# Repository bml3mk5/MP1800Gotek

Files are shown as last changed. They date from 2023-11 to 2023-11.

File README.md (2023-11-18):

# ディスクインターフェース for MP-1800 / MP-1805 on 日立ベーシックマスターレベル３

## フォルダ構成

    Board/ ......................... 基板設計(KiCAD Version 6)

-----
# Disk Interface for MP-1800 / MP-1805 on HITACH BASIC MASTER LEVEL3

## Folders:

    Board/ ......................... Circuit board design(KiCAD Version 6)

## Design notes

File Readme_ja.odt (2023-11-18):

# 日立ベーシックマスターレベル３用

# ディスクインターフェース for MP-1800 / MP-1805

Designed by Sasaji 2023 Rev. 0.2.2

フロッピーディスクドライブとFDインターフェースMP-1800 / MP-1805の間に接続する拡張ボードです。

日立ベーシックマスターレベル３/マークII/マーク5で使用できます。

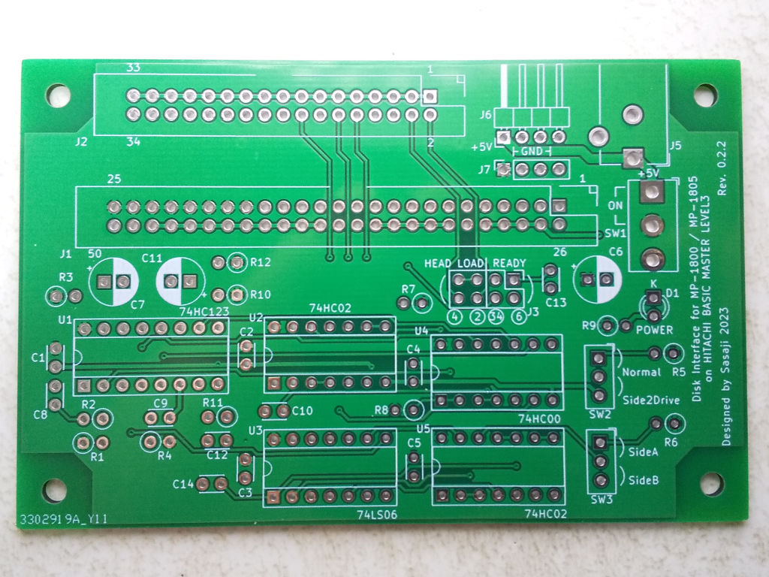
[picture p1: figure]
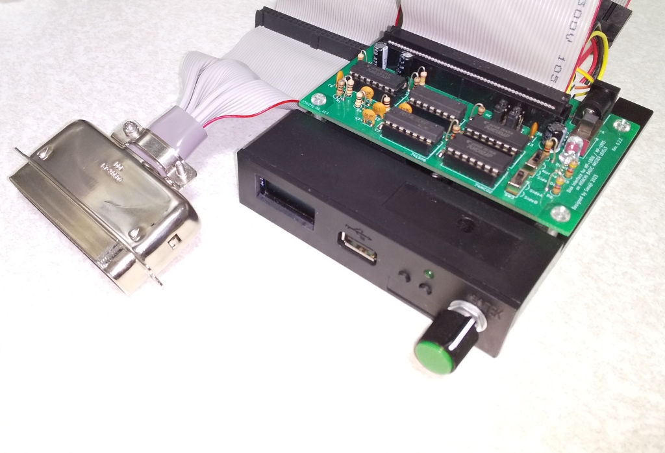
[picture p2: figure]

GOTEKを接続したところ

# 準備するもの

この基板を使用するには、以下のものを別途用意する必要があります。

- 本体側にFDインターフェースカード MP-1800またはMP-1805があること。
- FDDはエミュレータ(GOTEK)または2Dのもの。
- 電源：+5V, 1A以上（スイッチングACアダプタ など）
- 本体側と接続するケーブル：50ピンアンフェノール　⇔ 50ピン IDCコネクタ(2.54mmピッチ x2列)
- FDD側と接続するケーブル：34ピンIDCコネクタケーブル(2.54mmピッチ x2列)

# 各部の役割

電源入力 ＋５V DCジャック （中心が＋） 電源入力 ＋５V EIコネクタ (+5V,Gnd,Gnd,N/C) FDDと 接続 本体側と 接続 電源出力 ＋５V FDDに接続 （電源スイッチと連動） 電源スイッチ ジャンパー Side2Drive 切換スイッチ + - サイド 切換スイッチ

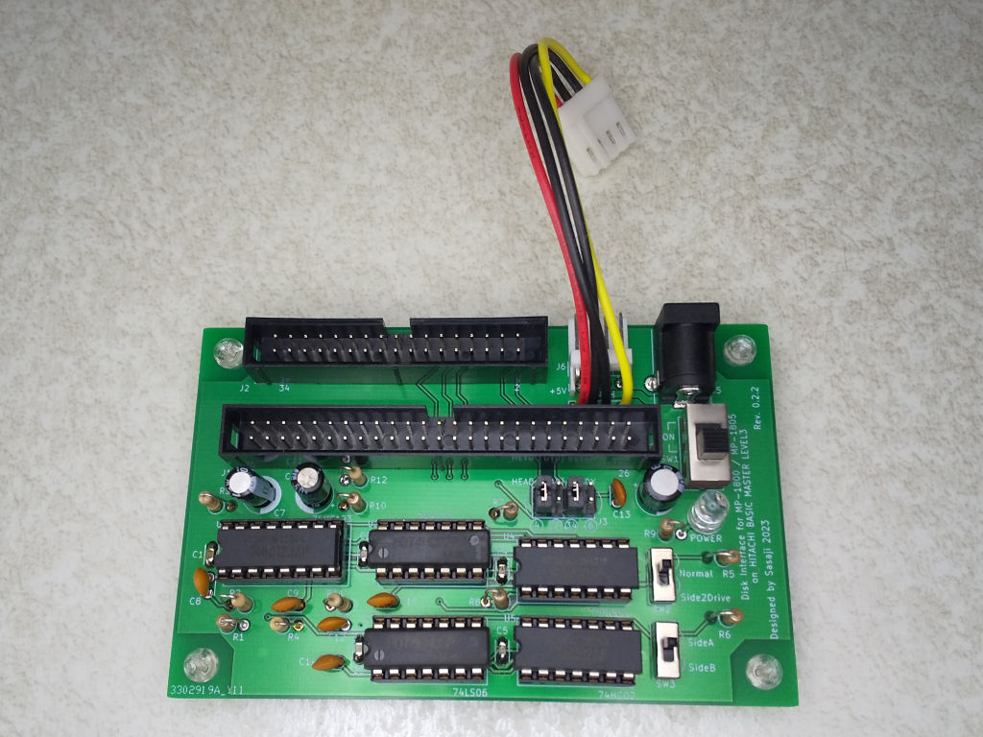
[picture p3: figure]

# ジャンパピン

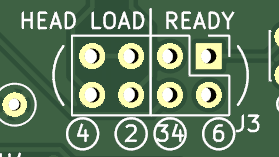
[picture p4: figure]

READY:

FDDからくるREADY信号がどのピンから来ているかを選択します。

ピン34 または ピン6

どちらかを縦方向にショートさせてください。

HEAD LOAD:

本体側からくるHEAD LOAD信号をどのピンに送るか選択します。

ピン4 または ピン2

どちらかを縦方向にショートさせてください。

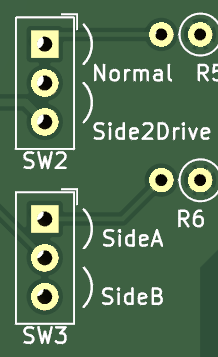
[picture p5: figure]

# 切換スイッチ

Side2Drive (SW2):

Side2Drive側に入れると、表面(サイド0)をドライブ0として裏面(サイド1)をドライブ1として扱います。

サイド切換 (SW3):

表面(サイド0)にアクセスする場合はSideAを、裏面(サイド1)にアクセスする場合はSideBを選択します。

【注意】Side2Driveを有効にしている場合、この設定は無視されます。

# コネクタのピン配置

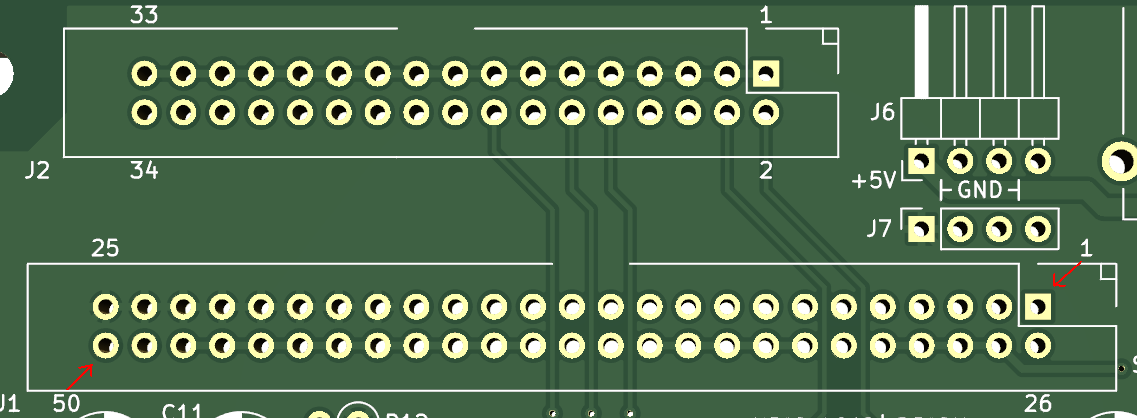
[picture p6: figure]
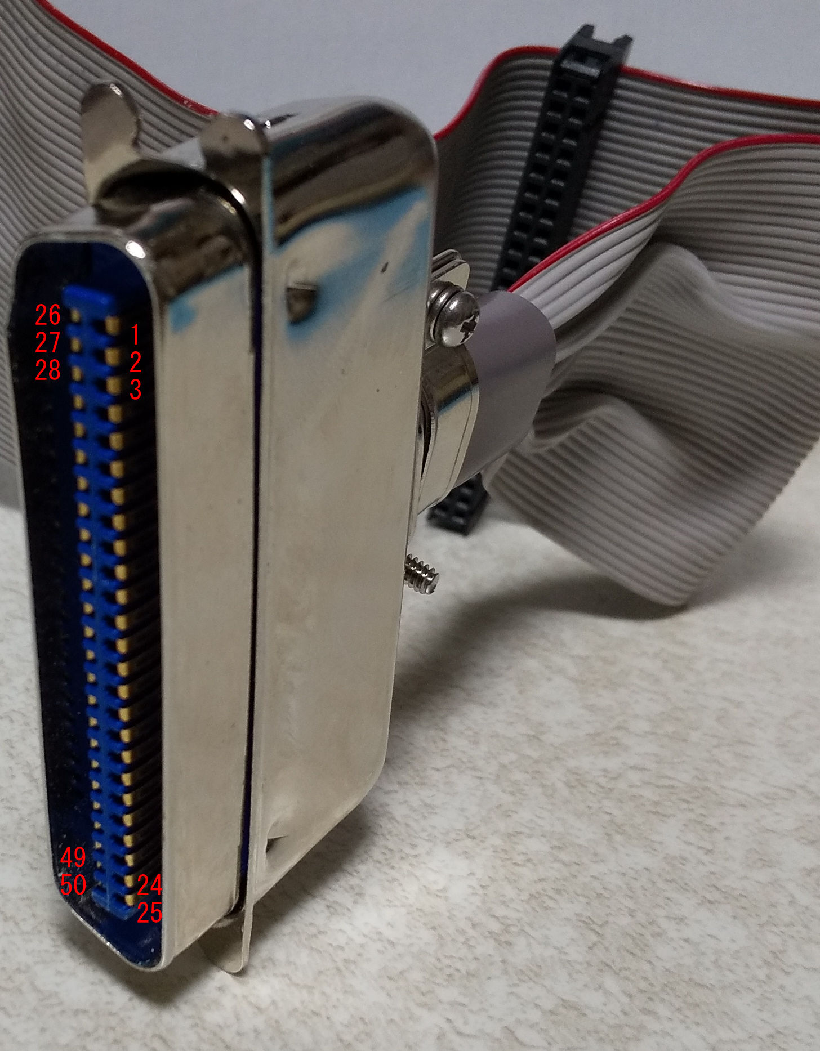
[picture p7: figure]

### 50ピンケーブル自作時の注意点

MP-1800 / MP-1805側には、ピン26近くに出っ張りがあるため、ケーブル側はこの部分をまげて出っ張りに当たらないようにします。

# 使用上の注意

- 電源入力J5(DCジャック)とJ6(EIコネクタ)はどちらか一方のみ接続してください。
- J6のピン4(+12Vライン)はどこにも接続していません。+12Vが必要なFDDを使用する場合、電源コネクタはこの基板を経由せずに接続してください。
- この基板は試作品です。使用中に発生するノイズや経年劣化などに対しての考慮は全くしていませんので予めご了承ください。

## 免責事項

この基板によって発生したいかなる損害についても当方は一切責任を負いません。

この基板を使用するにあたってはすべて自己責任で行ってください。

## Webページ

この資料や基板データなどはGitHub(https://github.com/bml3mk5/MP1800Gotek)に置いています。

連絡先：

Sasaji (sasaji@s-sasaji.ddo.jp)

http://s-sasaji.ddo.jp/bml3mk5/

(Twitter: https://twitter.com/bml3mk5)

## 改訂履歴

初版: 新規作成。

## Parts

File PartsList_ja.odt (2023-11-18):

# 日立ベーシックマスターレベル３用

# ディスクインターフェース for MP-1800 / MP-1805

Designed by Sasaji 2023 Rev. 0.2.2

# 部品表

番号 | 部品名 | 数量 | 値など
C1~C5 | セラミックコンデンサ | 5 | 0.1uF
C6 | 電解コンデンサ | 1 | 100uF, 10V～
C7, C11 | 電解コンデンサ | 2 | 10uF, 10V～
C8, C12 | セラミックコンデンサ | 2 | 330pF
C9, C10, C14 | セラミックコンデンサ | 3 | 1000pF
C13 | セラミックコンデンサ | 1 | 0.01uF
R1, R7, R8, R9, R10 | カーボン抵抗 | 5 | 1KΩ, 1/4W～
R2, R4, R11 | カーボン抵抗 | 3 | 10KΩ, 1/4W～
R3 | カーボン抵抗 | 1 | 330KΩ, 1/4W～
R5, R6 | カーボン抵抗 | 2 | 4.7KΩ, 1/4W～
R12 | カーボン抵抗 | 1 | 240KΩ, 1/4W～
U1 | CMOSロジックIC | 1 | 74HC123, DIP16ピン
U2, U5 | CMOSロジックIC | 2 | 74HC02, DIP14ピン
U3 | TTLロジックIC | 1 | 74LS06, DIP14ピン
U4 | CMOSロジックIC | 1 | 74HC00, DIP14ピン
D1 | LED | 1 | 電源ランプ 3mmΦ～
SW1 | 電源スイッチ | 1 | 1回路2接点 SS12D10など 4.7～5mmピッチ
SW2, SW3 | 切換スイッチ | 2 | 1回路2接点 SS12D00など 2.54mmピッチ
J1 | BOXヘッダ | 1 | 25ピンx2列 2.54mmピッチ ストレート
J2 | BOXヘッダ | 1 | 17ピンx2列 2.54mmピッチ ストレート
J3 | ジャンパ | 1 | ピンヘッダ 4ピンx2列 2.54mmピッチ ストレート
J5 | DCジャック | 1 | バレルジャック 2.1mmΦ PJ-102など
J6 | 電源コネクタ | 1 | EIコネクタ オス 4ピンx1列 Lアングル (3.5インチFDD用)

## 以下の部品はオプション

J7 | ケーブル接続 | 1 | 4本ケーブルを接続
* | FDD接続用コネクタ | 1 | EIコネクタ メス 4ピンx1列 ストレート J7からケーブルを介して接続

# オプション機能について

### J7について

J7はFDDエミュレータ(GOTEK)の電源ソケットに接続するための電源出力端子です。基板上の電源スイッチと連動しています。

ピン1:+5V ピン2,3:GND ピン4:未接続 【注意】+12Vとは接続していません。

## 免責事項

この基板によって発生したいかなる損害についても当方は一切責任を負いません。

この基板を使用するにあたってはすべて自己責任で行ってください。

## Webページ

この資料や基板データなどはGitHub(https://github.com/bml3mk5/MP1800Gotek)に置いています。

連絡先：

Sasaji (sasaji@s-sasaji.ddo.jp)

http://s-sasaji.ddo.jp/bml3mk5/

(Twitter: https://twitter.com/bml3mk5)

## 改訂履歴

初版: 新規作成。

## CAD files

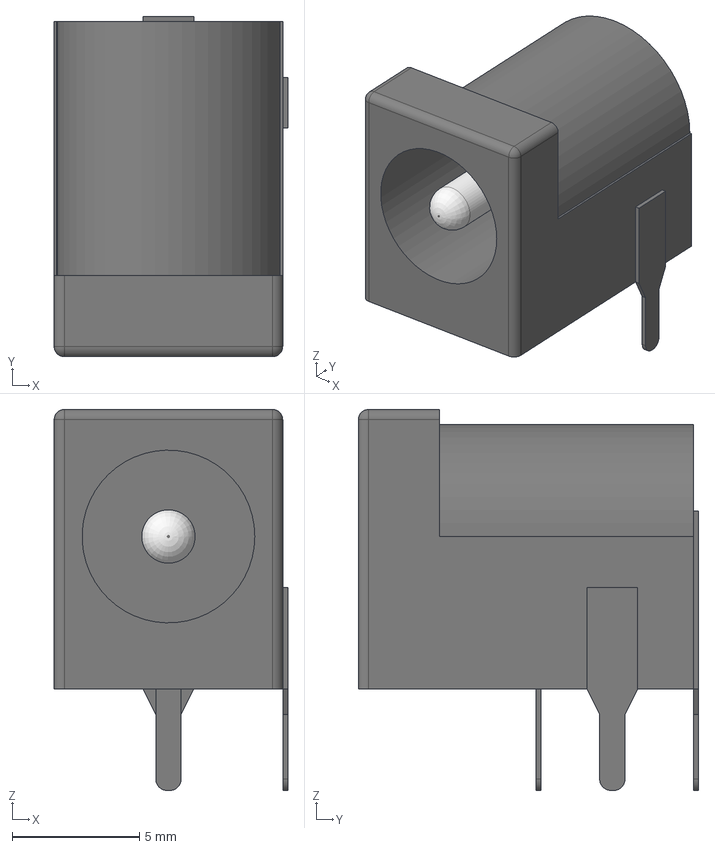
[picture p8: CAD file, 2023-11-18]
Board/DCJ21-Body.step
9.20 x 13.4 x 15.0 mm

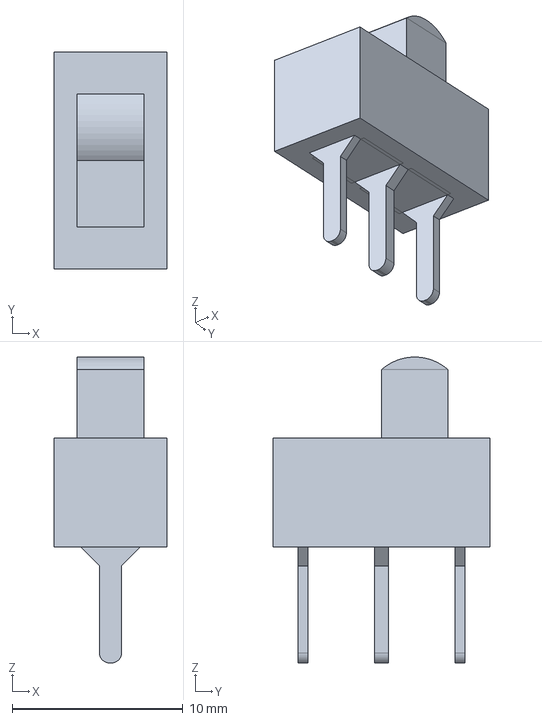
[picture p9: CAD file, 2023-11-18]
Board/SS12D10-Body.step
6.60 x 12.7 x 17.9 mm

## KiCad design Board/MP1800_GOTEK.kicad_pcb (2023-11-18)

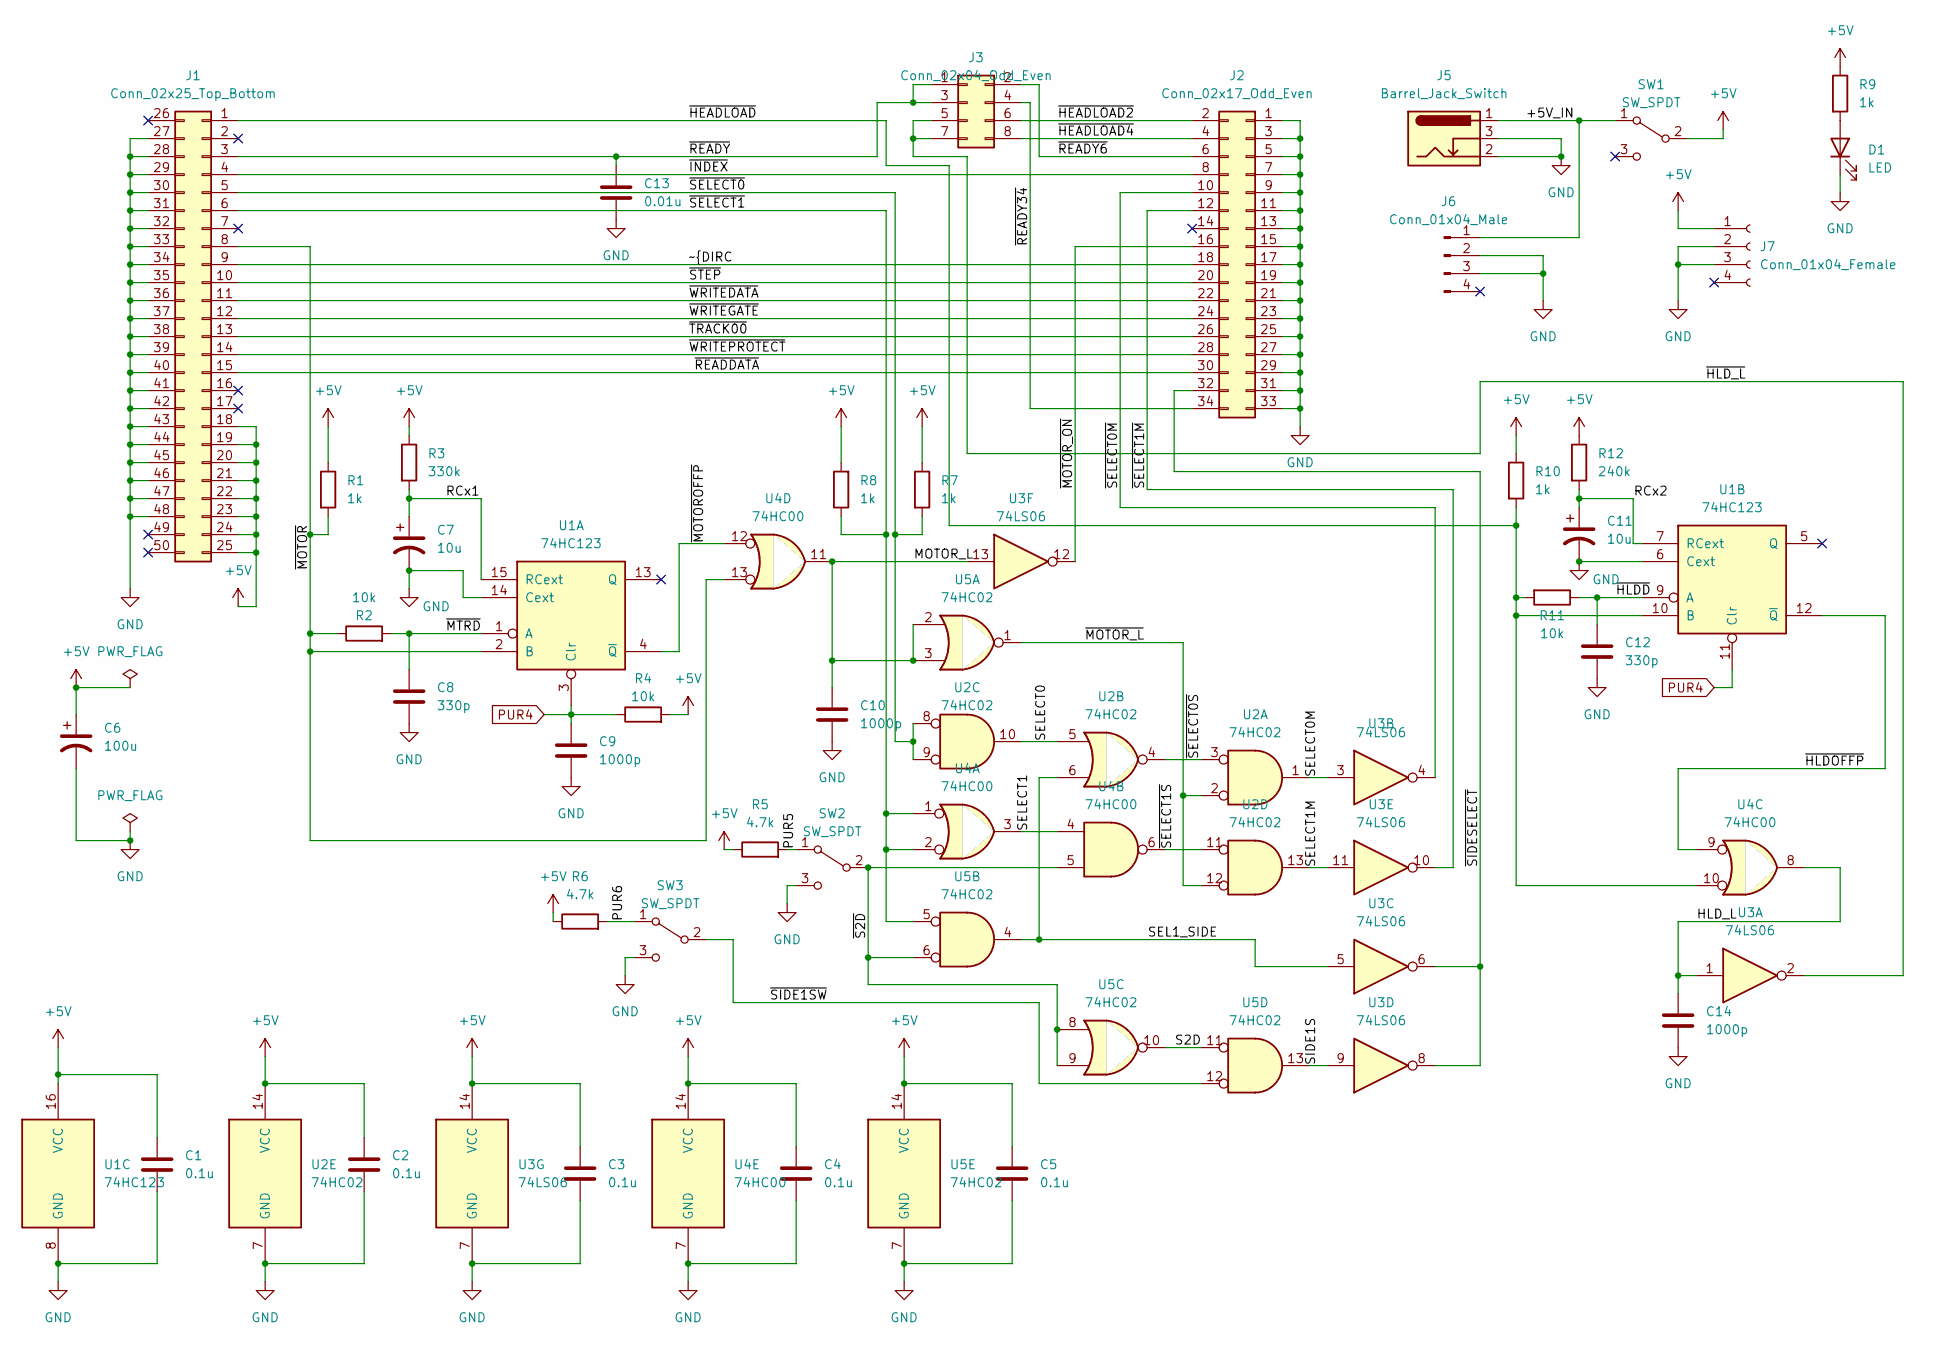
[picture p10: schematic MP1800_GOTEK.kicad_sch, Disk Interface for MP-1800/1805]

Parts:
C1, C2, C3, C4, C5: 0.1u; C_Disc_D3.0mm_W2.0mm_P2.50mm
C6: 100u; CP_Radial_D6.3mm_P2.50mm
C7, C11: 10u; CP_Radial_D6.3mm_P2.50mm
C8, C12: 330p; C_Disc_D3.0mm_W2.0mm_P2.50mm
C9, C10, C14: 1000p; C_Disc_D3.0mm_W2.0mm_P2.50mm
C13: 0.01u; C_Disc_D3.0mm_W2.0mm_P2.50mm
D1: LED; LED_D3.0mm
J1: Conn_02x25_Top_Bottom; YA_PinHeader_2x25_P2.54mm_Vertical
J2: Conn_02x17_Odd_Even; YA_PinHeader_2x17_P2.54mm_Vertical
J3: Conn_02x04_Odd_Even; PinHeader_2x04_P2.54mm_Vertical
J5: Barrel_Jack_Switch; YA_BarrelJack_CUI_PJ-102AH_Horizontal
J6: Conn_01x04_Male; PinHeader_1x04_P2.54mm_Horizontal
J7: Conn_01x04_Female; PinSocket_1x04_P2.54mm_Vertical
R1, R7, R8, R9, R10: 1k; R_Axial_DIN0207_L6.3mm_D2.5mm_P2.54mm_Vertical
R2, R4, R11: 10k; R_Axial_DIN0207_L6.3mm_D2.5mm_P2.54mm_Vertical
R3: 330k; R_Axial_DIN0207_L6.3mm_D2.5mm_P2.54mm_Vertical
R5, R6: 4.7k; R_Axial_DIN0207_L6.3mm_D2.5mm_P2.54mm_Vertical
R12: 240k; R_Axial_DIN0207_L6.3mm_D2.5mm_P2.54mm_Vertical
SW1: SW_SPDT; SW_Switch_SS12D10_SPDT
SW2, SW3: SW_SPDT; SW_Switch_SS12D00_SPDT
U1: 74HC123; DIP-16_W7.62mm_Socket
U2, U5: 74HC02; DIP-14_W7.62mm_Socket
U3: 74LS06; DIP-14_W7.62mm_Socket
U4: 74HC00; DIP-14_W7.62mm_Socket

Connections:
+5V: C1.2, C2.2, C3.2, C4.2, C5.2, C6.1, J1.18, J1.19, J1.20, J1.21, J1.22, J1.23, J1.24, J1.25, J7.1, R1.1, R3.1, R4.2, R5.1, R6.1, R7.1, R8.2, R9.1, R10.1, R12.1, SW1.2 (B), U1.16 (VCC), U2.14 (VCC), U3.14 (VCC), U4.14 (VCC), U5.14 (VCC)
/+5V_IN: J5.1, J6.1, SW1.1 (A)
/HLD_L: C14.2, U3.1, U4.8
/MOTOR_L: C10.2, U3.13, U4.11, U5.2, U5.3
/PUR5: R5.2, SW2.1 (A)
/PUR6: R6.2, SW3.1 (A)
/RCx1: C7.1, R3.2, U1.15 (RCext)
/RCx2: C11.1, R12.2, U1.7 (RCext)
/S2D: U5.10, U5.11
/SEL1_SIDE: U2.6, U3.5, U5.4
/SELECT0: U2.5, U2.10
/SELECT0M: U2.1, U3.3
/SELECT1: U4.3, U4.4
/SELECT1M: U2.13, U3.11
/SIDE1S: U3.9, U5.13
/~DIRC: J1.9, J2.18
/~HEADLOAD2: J2.2, J3.6
/~HEADLOAD4: J2.4, J3.8
/~HEADLOAD: J1.1, R10.2, R11.2, U1.10 (B), U4.10
/~HLDD: C12.2, R11.1, U1.9 (A)
/~HLDOFFP: U1.12 (~Q), U4.9
/~HLD_L: J3.5, J3.7, U3.2
/~INDEX: J1.4, J2.8
/~MOTOROFFP: U1.4 (~Q), U4.12
/~MOTOR_L: U2.2, U2.12, U5.1
/~MOTOR_ON: J2.16, U3.12
/~MOTOR: J1.8, R1.2, R2.1, U1.2 (B), U4.13
/~MTRD: C8.2, R2.2, U1.1 (A)
/~READDATA: J1.15, J2.30
/~READY6: J2.6, J3.2
/~READY34: J2.34, J3.4
/~READY: C13.2, J1.3, J3.1, J3.3
/~S2D: SW2.2 (B), U4.5, U5.6, U5.8, U5.9
/~SELECT0M: J2.10, U3.4
/~SELECT0S: U2.3, U2.4
/~SELECT0: J1.5, R7.2, U2.8, U2.9
/~SELECT1M: J2.12, U3.10
/~SELECT1S: U2.11, U4.6
/~SELECT1: J1.6, R8.1, U4.1, U4.2, U5.5
/~SIDE1SW: SW3.2 (B), U5.12
/~SIDESELECT: J2.32, U3.6, U3.8
/~STEP: J1.10, J2.20
/~TRACK00: J1.13, J2.26
/~WRITEDATA: J1.11, J2.22
/~WRITEGATE: J1.12, J2.24
/~WRITEPROTECT: J1.14, J2.28
GND: C1.1, C2.1, C3.1, C4.1, C5.1, C6.2, C7.2, C8.1, C9.1, C10.1, C11.2, C12.1, C13.1, C14.1, D1.1 (K), J1.27, J1.28, J1.29, J1.30, J1.31, J1.32, J1.33, J1.34, J1.35, J1.36, J1.37, J1.38, J1.39, J1.40, J1.41, J1.42, J1.43, J1.44, J1.45, J1.46, J1.47, J1.48, J2.1, J2.3, J2.5, J2.7, J2.9, J2.11, J2.13, J2.15, J2.17, J2.19, J2.21, J2.23, J2.25, J2.27, J2.29, J2.31, J2.33, J5.2, J5.3, J6.2, J6.3, J7.2, J7.3, SW2.3 (C), SW3.3 (C), U1.6 (Cext), U1.8 (GND), U1.14 (Cext), U2.7 (GND), U3.7 (GND), U4.7 (GND), U5.7 (GND)
unnamed: D1.2 (A), R9.2
PUR4: C9.2, R4.1, U1.3 (Clr), U1.11 (Clr)

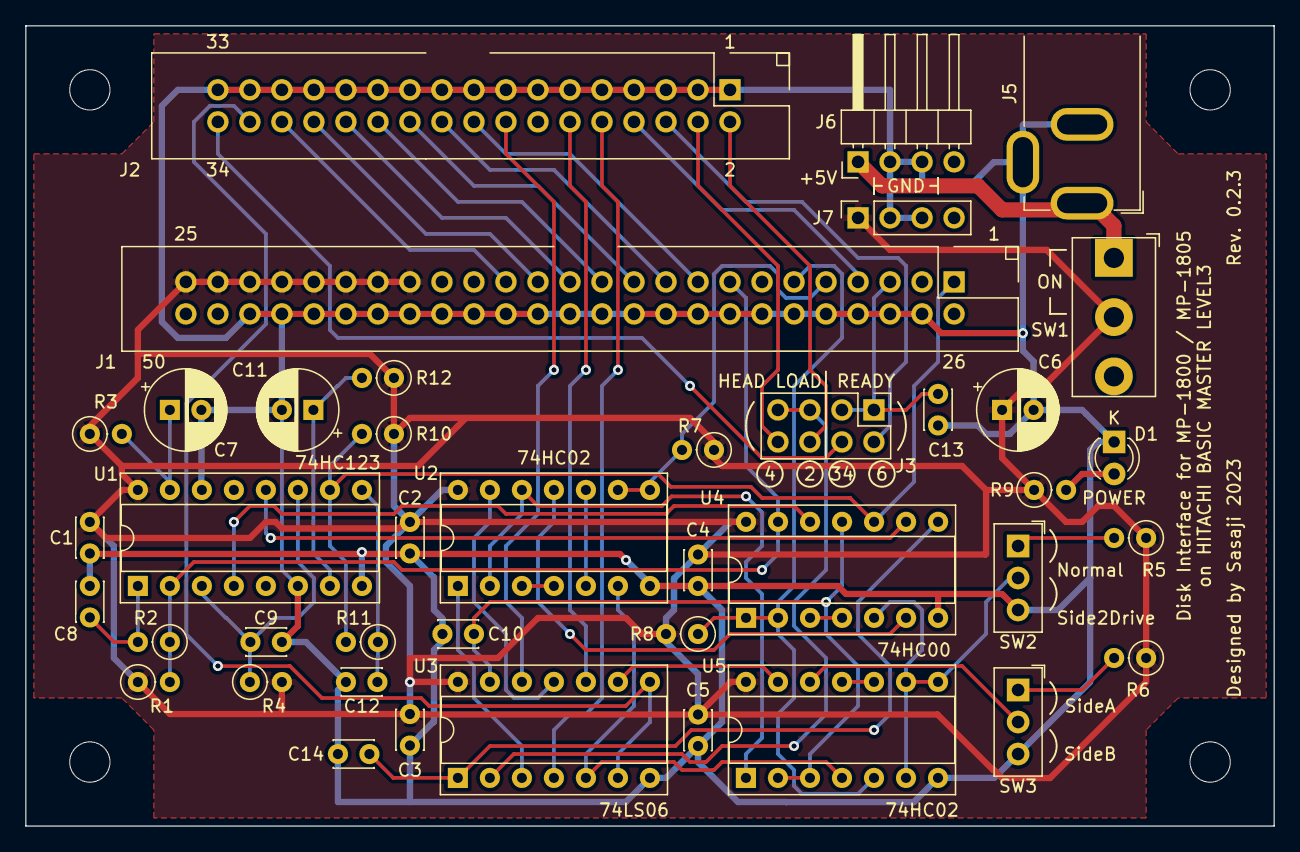
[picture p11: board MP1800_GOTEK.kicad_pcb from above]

Board: 2 copper layers, 99.1 x 63.5 mm, 41 parts (0 on the bottom side), 49 nets.

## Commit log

2023-11-18 Version 0.2.2
    [DCJ21-Body.step, MP1800_GOTEK.kicad_pcb, MP1800_GOTEK.kicad_sch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]
2023-11-18 Revision 0.2.3
    [MP1800_GOTEK.kicad_pcb, MP1800_GOTEK.kicad_sch]
